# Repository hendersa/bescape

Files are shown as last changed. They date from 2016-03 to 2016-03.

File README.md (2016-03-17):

# bescape
Beagle Entertainment System hardware cape files for EAGLE PCB

The BESCape is a BeagleBone Black cape board designed to be used with
the Beagle Entertainment System (http://beaglesnes.org) software system.
BESCape is a hardware interface that provides the BES software with a
DS1307 battery-backed RTC and two Super Nintendo controller connectors. 
This allows a BeagleBone Black running BES to more effectively serve as
a retrogaming console.

The cape uses the following pins:

1. P8.01: GND       (Grounding plane)
2. P8.02: GND       (Grounding plane)
3. P8.26: GPIO1_29  (GPIO for Gamepad2 DATA signal)
4. P9.01: GND       (Grounding plane)
5. P9.02: GND       (Grounding plane)
6. P9.03: VDD_3V3   (3.3VDC to gamepad line-level converter FETs)
7. P9.04: VDD_3V3   (3.3VDC to RTC and EEPROM)
8. P9.05: VDD_5V    (5.0VDC to gamepad line-level converter FETs)
9. P9.06: VDD_5V    (5.0VDC to gamepad line-level converter FETs)
10. P9.11: UART4_RXD (GPIO for Gamepad1/2 CLOCK signal)
11. P9.12: GPIO1_28  (GPIO for Gamepad1 DATA signal)
12. P9.13: UART4_TXD (GPIO for Gamepad1/2 LATCH signal)
13. P9.17: I2C1_SCL  (I2C SCL for RTC)
14. P9.18: I2C1_SDA  (I2C SDA for RTC)
15. P9.19: I2C2_SCL  (I2C SCL for cape EEPROM)
16. P9.20: I2C2_SDA  (I2C SDA for cape EEPROM)
17. P9.22: UART2_RXD (GPIO for menu/pause switch signal)
18. P9.27: GPIO3_19  (GPIO for menu/pause LED)
19. P9.43: GND       (Grounding plane)
20. P9.44: GND       (Grounding plane)
21. P9.45: GND       (Grounding plane)
22. P9.46: GND       (Grounding plane)

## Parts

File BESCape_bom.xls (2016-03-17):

Bill Of Materials For Beagle Entertainment System Cape Board
MAIN PARTS: |  |  |  |  |  |  |  |  |  | For 50
Qty | Value | Parts | Package | Digikey Part | Unit Price | Extended Price | Description
1 | N/A | SW1 | DIPSWITCH-02 | CT2092MS-ND | $0.55 | $0.55 | DIP Switch (Two switches) | 15 |  | 35
2 | 0.1uF | C1, C2 | C0805 | 1276-1007-1-ND | $0.03 | $0.06 | Capacitor | 100 |  | 0
9 | 10k | R3, R4, R5, R6, R7, R8, R9, R10, R16 | R0805 | 311-10KARCT-ND | $0.02 | $0.16 | Resistor | 1000 |  | 0
2 | 2.2k | R1, R2 | R0805 | 311-2.2KARCT-ND | $0.02 | $0.04 | Resistor | 1000 |  | 0
1 | 24C256 | IC1 | DIL08 | 1219-1052-ND | $0.88 | $0.88 | 2-wire serial EEPROM | 25 |  | 25
1 | 32.768KHz | XTAL1 | TC38H | 535-9034-ND | $0.21 | $0.21 | Crystal | 15 |  | 35
1 | N/A | RTC_BAT | CR1220-SMD | 952-1662-1-ND | $0.51 | $0.51 | CR1216/CR1220/CR1225 12mm coin cell holder | 15 |  | 35
1 | 3V | RTC_BAT | CR1220 | SY033-ND | $0.62 | $0.62 | CR1220 battery | 15 |  | 35
3 | 4.75k | R13, R14, R15 | R0805 | 311-4.75KCRCT-ND | $0.02 | $0.06 | Resistor | 1000 |  | 0
2 | 5.6k | R11, R12 | R0805 | 311-5.6KARCT-ND | $0.02 | $0.04 | Resistor | 1000 |  | 0
4 | BSS138 | Q1, Q2, Q3, Q4 | SOT23 | BSS138CT-ND | $0.23 | $0.92 | Fairchild Semiconductors BSS138 N-Channel MOSFET | 100 |  | 100
1 | DS1307 | IC2 | DIL08 | DS1307+-ND | $3.37 | $3.37 | DS1307 Realtime Clock | 15 |  | 35
2 | N/A | GAMEPAD1/2 | N/A | * Order from Raphnet | $1.25 | $2.50 | Generic SNES connector | 10x4 | 70CAD | 15x4
1 | N/A | SW2 | EVQ-Q2 | P12931SCT-ND | $0.40 | $0.40 | SMT 6mm switch | 25 |  | 25
1 | N/A | LED1 | 1206P | 160-1404-1-ND | $0.29 | $0.29 | LED Green clear 1206 SMD | 15 |  | 35
2 | N/A | P8, P9 | N/A | S2012EC-23-ND | $0.79 | $1.58 | Cape header, 2x23 pins | 26 |  | 74
 |  |  |  | Subtotal: |  | 12.187
EXTRAS:
Qty | Value | Parts | Package | Digikey Part | Unit Price | Extended Price | Description
2 | N/A | IC1, IC2 | DIP Socket-8PIN | AE9986-ND | $0.18 | $0.36 | Sockets for DS1307 and 24C256 ICs
 |  |  |  | Subtotal: |  | 0.36
 |  |  |  | Total: |  | 12.547
 |  | * www.raphnet-tech.com
 |  | Item #250025-4

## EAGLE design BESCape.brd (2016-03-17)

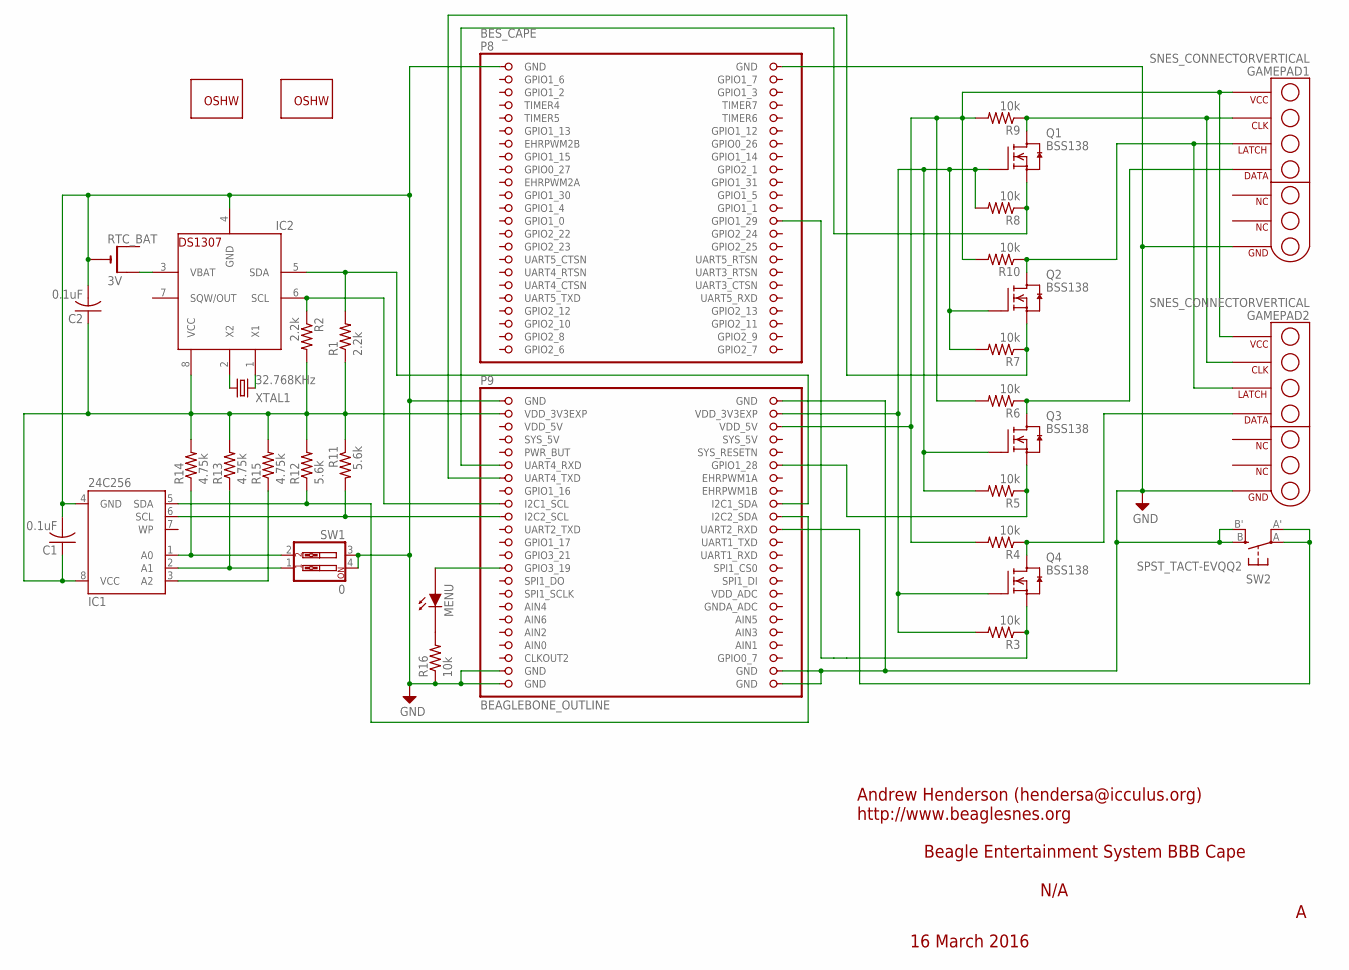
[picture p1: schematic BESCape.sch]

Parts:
BES_CAPE: BEAGLEBONE_OUTLINE; BEAGLEBONE_SHIELD
C1, C2: 0.1uF; C0805
GAMEPAD1, GAMEPAD2: SNES_CONNECTORVERTICAL; SNES_CONNECTOR_VERTICAL
GOLD_ORB_SM1: OSHWLOGO_GOLD_ORB_LG; OSHW0
GOLD_ORB_SM3: OSHWLOGO_GOLD_ORB_SM; OSHW2
IC1: 24C256; DIL08
IC2: DS1307; DIL08
MENU: LEDD; 1206P
Q1, Q2, Q3, Q4: BSS138; SOT23
R1, R2: 2.2k; R0805
R3, R4, R5, R6, R7, R8, R9, R10, R16: 10k; R0805
R11, R12: 5.6k; R0805
R13, R14, R15: 4.75k; R0805
RTC_BAT: 3V; CR1220-SMD
SW1: 0; DIPSWITCH-02
SW2: SPST_TACT-EVQQ2; EVQ-Q2
XTAL1: 32.768KHz; TC38H

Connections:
AIN0: BES_CAPE.85 (AIN0)
GND: BES_CAPE.1 (GND), BES_CAPE.2 (GND), BES_CAPE.47 (GND), BES_CAPE.48 (GND), BES_CAPE.89 (GND), BES_CAPE.90 (GND), BES_CAPE.91 (GND), BES_CAPE.92 (GND), C1.2, C2.2, GAMEPAD1.P$17 (GND), GAMEPAD2.P$17 (GND), IC1.4 (GND), IC2.4 (GND), R16.1, RTC_BAT.-, SW1.3, SW1.4, SW2.B (S), SW2.B' (S1)
unnamed: BES_CAPE.26 (GPIO1_29), Q4.2 (S), R3.1
unnamed: MENU.2 (D_OUT), R16.2
unnamed: BES_CAPE.73 (GPIO3_19), MENU.1 (D_IN)
unnamed: BES_CAPE.64 (I2C1_SDA), IC2.5 (SDA), R1.2
unnamed: GAMEPAD1.P$13 (LATCH), GAMEPAD2.P$13 (LATCH), Q2.3 (D), R10.1
unnamed: IC2.2 (X2), XTAL1.1
unnamed: IC2.1 (X1), XTAL1.2
unnamed: GAMEPAD1.P$12 (CLK), GAMEPAD2.P$12 (CLK), Q1.3 (D), R9.1
unnamed: BES_CAPE.58 (GPIO1_28), Q3.2 (S), R5.1
unnamed: BES_CAPE.59 (UART4_TXD), Q2.2 (S), R7.1
unnamed: BES_CAPE.68 (UART2_RXD), SW2.A, SW2.A' (P1)
unnamed: IC1.3 (A2), R15.1
unnamed: IC1.2 (A1), R13.1, SW1.1
unnamed: BES_CAPE.63 (I2C1_SCL), IC2.6 (SCL), R2.1
unnamed: GAMEPAD2.P$14 (DATA), Q4.3 (D), R4.1
unnamed: GAMEPAD1.P$14 (DATA), Q3.3 (D), R6.1
unnamed: IC1.1 (A0), R14.1, SW1.2
unnamed: BES_CAPE.65 (I2C2_SCL), IC1.6 (SCL), R11.2
unnamed: BES_CAPE.66 (I2C2_SDA), IC1.5 (SDA), R12.1
PRU_CLOCK: BES_CAPE.57 (UART4_RXD), Q1.2 (S), R8.1
SYS_5V: BES_CAPE.53 (SYS_5V)
VBAT: IC2.3 (VBAT), RTC_BAT.+$2 (+1)
VCC: BES_CAPE.49 (VDD_3V3EXP), C1.1, C2.1, IC1.8 (VCC), IC2.8 (VCC), R1.1, R2.2, R11.1, R12.2, R13.2, R14.2, R15.2
VDD_3V3EXP: BES_CAPE.50 (VDD_3V3EXP), Q1.1 (G), Q2.1 (G), Q3.1 (G), Q4.1 (G), R3.2, R5.2, R7.2, R8.2
VDD_5V: BES_CAPE.51 (VDD_5V), BES_CAPE.52 (VDD_5V), GAMEPAD1.P$11 (VCC), GAMEPAD2.P$11 (VCC), R4.2, R6.2, R9.2, R10.2

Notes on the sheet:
Andrew Henderson (hendersa@icculus.org) http://www.beaglesnes.org
N/A
Beagle Entertainment System BBB Cape
16 March 2016

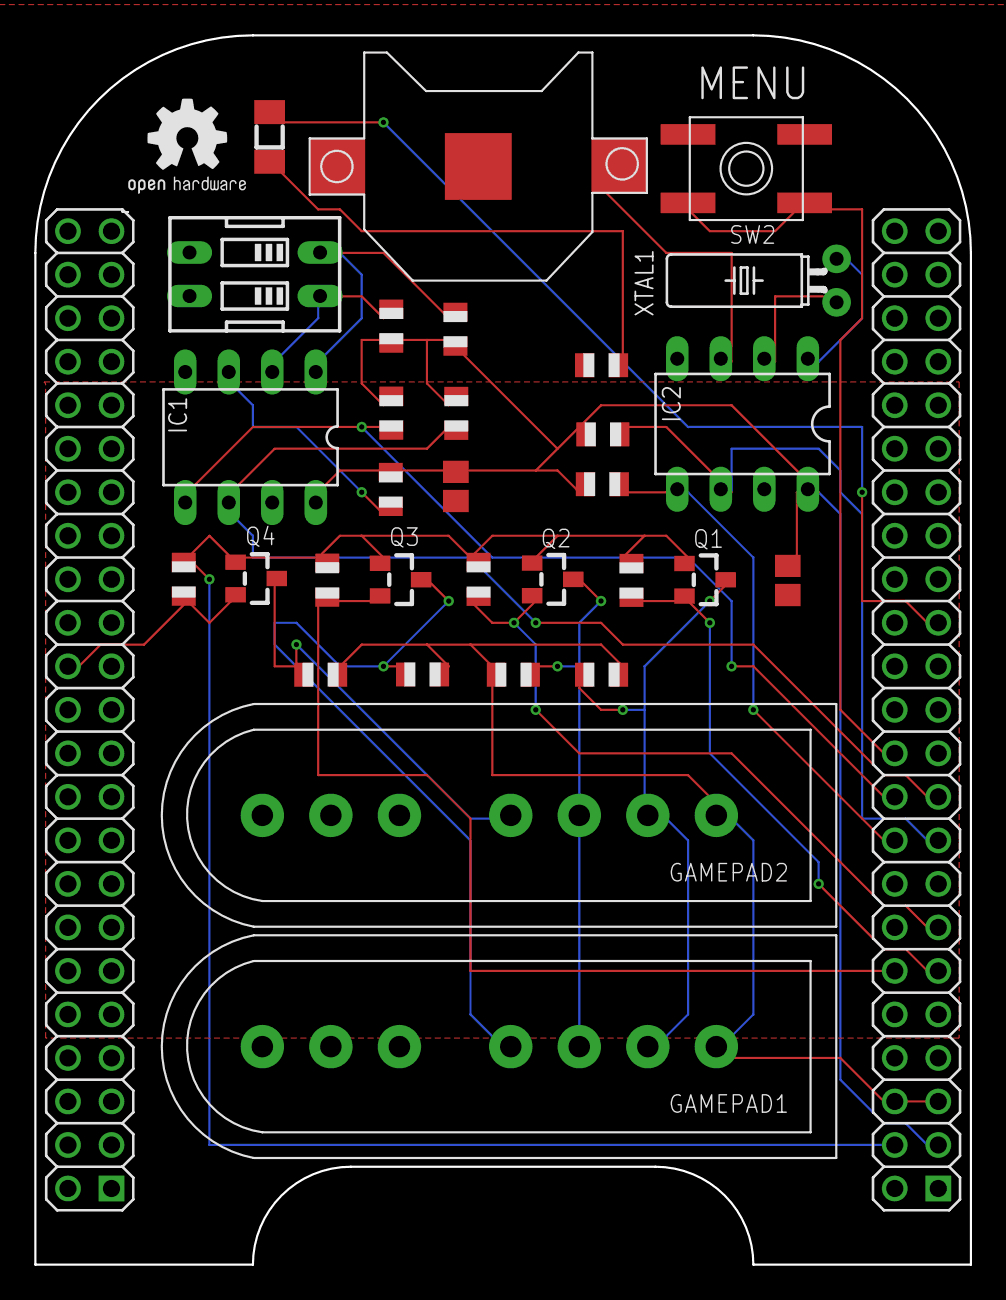
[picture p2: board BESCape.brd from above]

Board: 2 copper layers, 54.6 x 71.8 mm, 34 parts (1 on the bottom side), 25 nets.

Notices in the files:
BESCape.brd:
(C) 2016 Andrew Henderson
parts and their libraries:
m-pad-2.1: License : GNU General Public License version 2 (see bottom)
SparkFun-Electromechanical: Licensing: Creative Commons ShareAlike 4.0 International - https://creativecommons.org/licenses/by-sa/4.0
